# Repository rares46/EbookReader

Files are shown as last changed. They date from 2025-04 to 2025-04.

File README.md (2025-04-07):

# EbookReader
OpenBook eBook Reader

Dispozitivul e-book se bazeaza pe un microcontroller ESP32-C6 si include un afisaj E-Paper.

[Diagrama Bloc](Images/diagram.png)

`Diagrama bloc afiseaza componente:`
- ESP32-C6 (unitate centrala)
- Afisaj E-Paper
- Cititor SD card
- RTC DS3231
- Senzor ambiental BME688
- Control incarcare baterie Li-Po
- Modul flash extern 64MB
- Interfata USB-C
- Circuit de reglare tensiune (LDO)

### BOM - Bill Of Materials

[Fisier BOM](Manufacturing/BOM.csv)
https://ro.mouser.com/
https://www.comet.srl.ro/

Alimentare
- Alimentare principala prin USB-C.
- Reglator de tensiune LDO (IC4 - XC6204A33) pentru conversia de la 5V la 3.3V.
  
Microcontroller
- ESP32-C6 = unitatea principala ce controleaza restul pieselor.
- Se ocupa cu gestionarea interfetei cu utilizatorul, afisajul EPD, comunicatia cu SD card-ul, RTC si senzorul ambiental.
  
Stocare
- Slot microSD pentru stocare.
- Memorie flash externa W25Q512JVSIQ conectata prin SPI pentru firmware suplimentar sau caching.

### Alocarea pinilor ESP32-C6

| Functie | Pin ESP32-C6 | Observatii |
|---|---|---|
| SD Card | IO2, IO3, IO4, IO5 | SPI |
| E-Paper Display | IO8, IO9, IO10 | SPI |
| Senzor BME688 | IO6 (SCL), IO7 (SDA) | I2C |
| RTC DS3231 | IO6 (SCL), IO7 (SDA) | I2C shared |
| Flash extern SPI | IO0, IO1, IO2 | SPI |
| Boot Button | IO9 | Reset GPIO |
| Buton IO | IO10 | Control interfata |
| UART Debug | IO20 (TX), IO21 (RX) | Conexiune seriala |
| Ecran Type Select | IO18, IO19 | Selectare tip e-paper |

Bugs: La piesa SAMACSYS_PARTS_USB4110GFA erori cu Board OUtline Clearance, care sunt datorate piesei cel mai probabil si din cand in cand eorare de Overlap la fir. Daca scot firul si il pun la loc dispare.
La piesa IND_4828-WE-TPC_WRE 2 erori Copper Width, care probabil sunt de la piesa.
  
La directorul images din proiect sunt imagini cu schematic ul, pcb si 3d si diagrama.

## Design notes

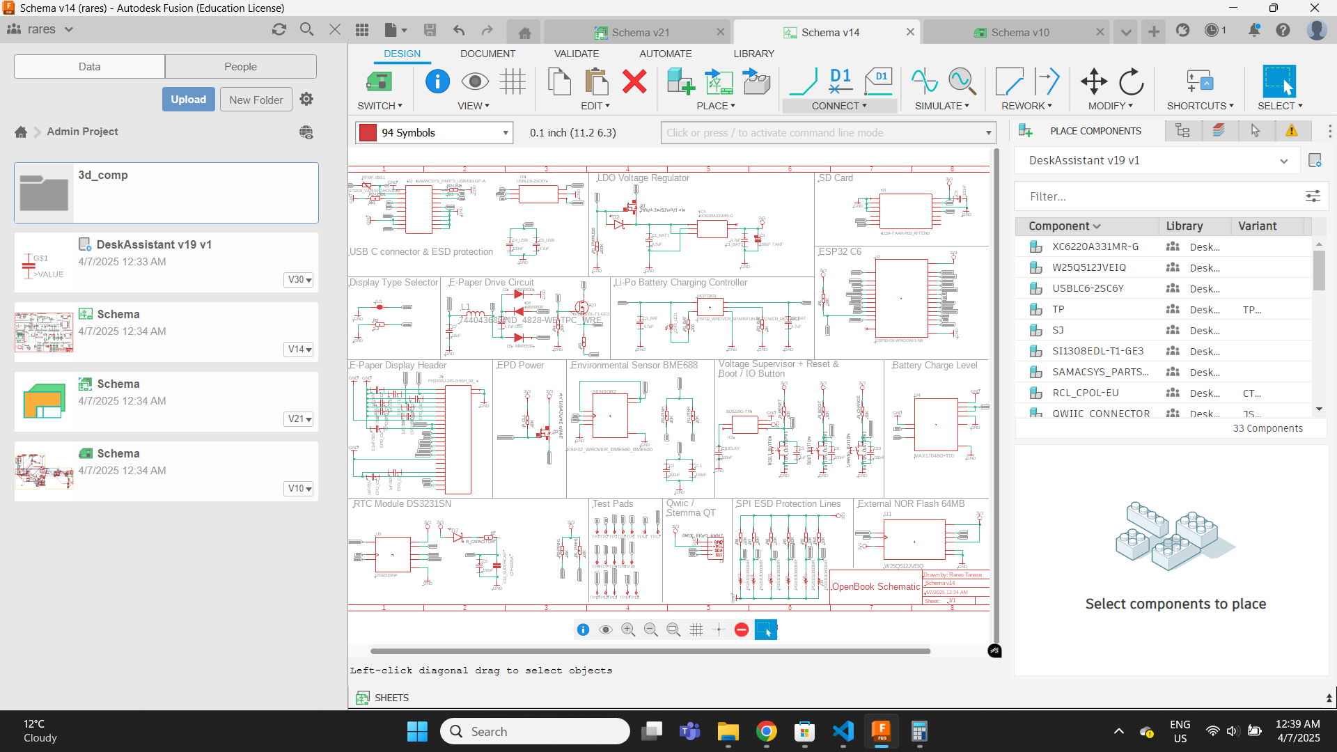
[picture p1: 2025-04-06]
Images/Schematic.png

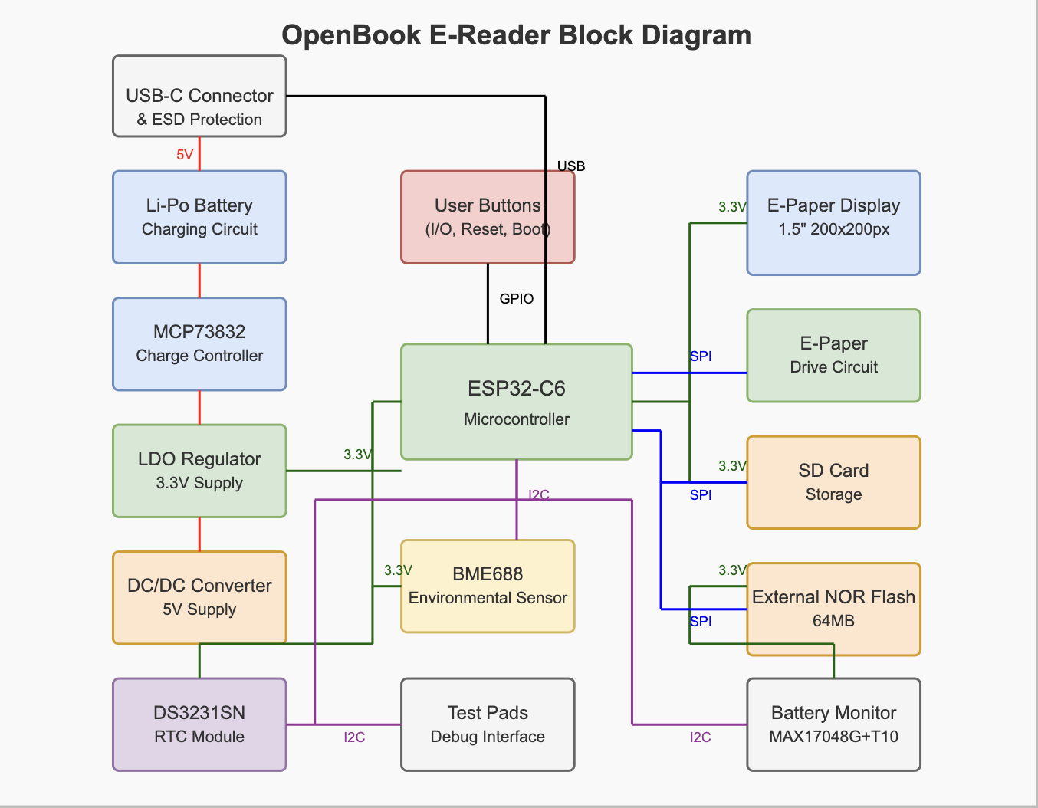
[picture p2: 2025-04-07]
Images/diagram.png

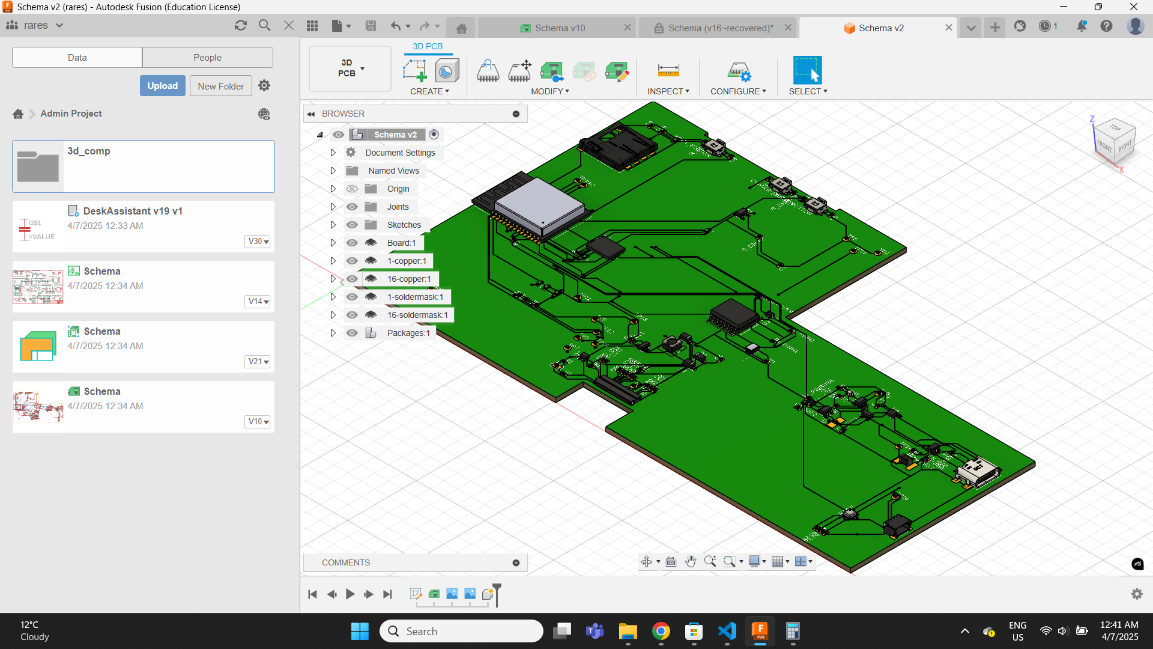
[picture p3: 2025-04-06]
Images/Board.png

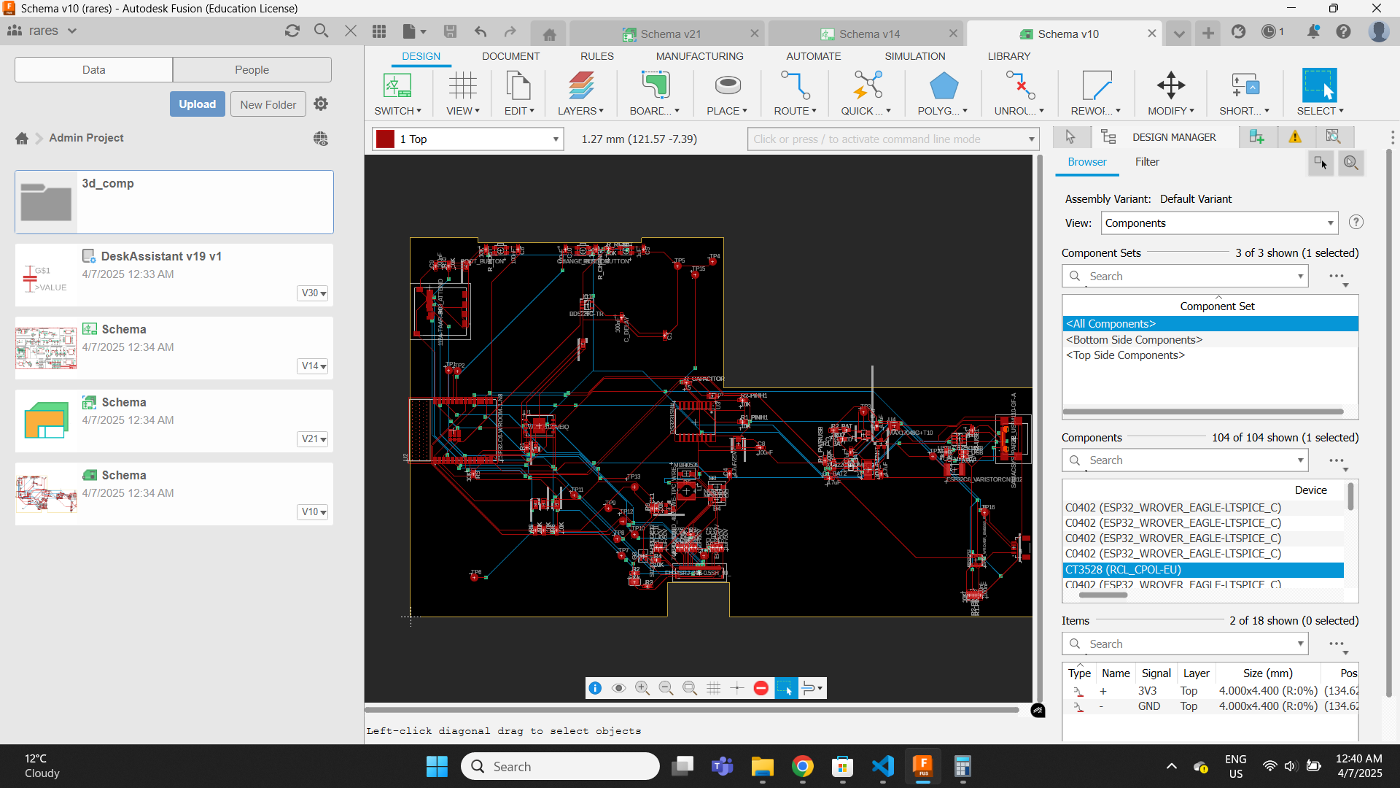
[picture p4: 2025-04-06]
Images/PCB.png

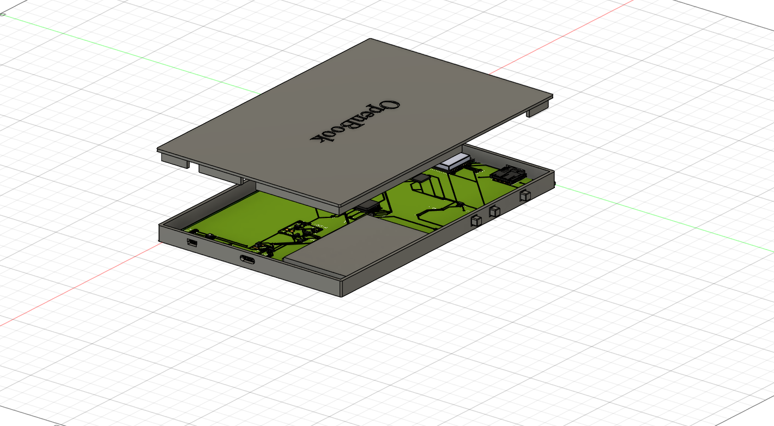
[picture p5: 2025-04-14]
Images/OpenBook Enclosure v1.png

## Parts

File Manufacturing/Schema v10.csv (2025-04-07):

Qty | Value | Device | Package | Parts | Description | ARROW_PART_NUMBER | ARROW_PRICE-STOCK | AVAILABILITY | CENTROID_NOT_SPECIFIED | CHECK_PRICES | COPYRIGHT | DATASHEET | DESCRIPTION | DIGIKEY_DESCRIPTION | DIGIKEY_PART_NUMBER | HEIGHT | LEAD_FREE | MANUFACTURER_NAME | MANUFACTURER_PART_NUMBER | MF | MFR_NAME | MOUSER_PART_NUMBER | MOUSER_PRICE-STOCK | MOUSER_TESTING_PART_NUMBER | MOUSER_TESTING_PRICE-STOCK | MP | MPN | PACKAGE | POPULARITY | PREFIX | PRICE | PROD_ID | PURCHASE-URL | ROHS | SNAPEDA_LINK | SPICEMODEL | SPICEPREFIX | TEMPERATURE_RANGE_HIGH | TEMPERATURE_RANGE_LOW | TP_SIGNAL_NAME | VALUE
1 |  | ADAFRUIT_LEDCHIP-LED0603 | ADAFRUIT_CHIP-LED0603 | CHG_LED | LED
1 |  | ESP32_WROVER_EAGLE-LTSPICE_CC0402 | ESP32_WROVER_EAGLE-LTSPICE_C0402 | C1 | CAPACITOR, European symbol |  |  |  |  |  |  |  |  |  |  |  |  |  |  |  |  |  |  |  |  |  |  |  |  |  |  |  |  |  |  | NONE | C
1 |  | ESP32_WROVER_EAGLE-LTSPICE_RR0402 | ESP32_WROVER_EAGLE-LTSPICE_R0402 | R3 | RESISTOR, European symbol |  |  |  |  |  |  |  |  |  |  |  |  |  |  |  |  |  |  |  |  |  |  |  |  |  |  |  |  |  |  | NONE | R
1 |  | SJ | SJ | SJ1 | SMD solder JUMPER |  |  |  |  |  |  |  |  |  |  |  |  |  |  |  |  |  |  |  |  |  |  |  | 3
1 | 0.1uF/50V | ESP32_WROVER_EAGLE-LTSPICE_CC0402 | ESP32_WROVER_EAGLE-LTSPICE_C0402 | EPD_C5 | CAPACITOR, European symbol |  |  |  |  |  |  |  |  |  |  |  |  |  |  |  |  |  |  |  |  |  |  |  |  |  |  |  |  |  |  | NONE | C
1 | 100K | ESP32_WROVER_EAGLE-LTSPICE_RR0402 | ESP32_WROVER_EAGLE-LTSPICE_R0402 | R1_PWRUSB | RESISTOR, European symbol |  |  |  |  |  |  |  |  |  |  |  |  |  |  |  |  |  |  |  |  |  |  |  |  |  |  |  |  |  |  | NONE | R
8 | 100nF | ESP32_WROVER_EAGLE-LTSPICE_CC0402 | ESP32_WROVER_EAGLE-LTSPICE_C0402 | C.1, C2, C4_USB, C6, C8, C9, C10, C_DELAY | CAPACITOR, European symbol |  |  |  |  |  |  |  |  |  |  |  |  |  |  |  |  |  |  |  |  |  |  |  |  |  |  |  |  |  |  | NONE | C
1 | 100uF TANT | RCL_CPOL-EUCT3528 | RCL_CT3528 | C3 | POLARIZED CAPACITOR, European symbol |  |  |  |  |  |  |  |  |  |  |  |  |  |  |  |  |  |  |  |  |  |  |  | 0 |  |  |  |  |  |  |  | C
16 | 10K | ESP32_WROVER_EAGLE-LTSPICE_RR0402 | ESP32_WROVER_EAGLE-LTSPICE_R0402 | R1, R1-PINH, R1_PINH1, R2-PINH, R2-PINH1, R4, R5, R6, R7, R8, R9, R10, R_BOOT, R_CHANGE, R_CL1, R_RESET | RESISTOR, European symbol |  |  |  |  |  |  |  |  |  |  |  |  |  |  |  |  |  |  |  |  |  |  |  |  |  |  |  |  |  |  | NONE | R
1 | 10uF | ESP32_WROVER_EAGLE-LTSPICE_CC0402 | ESP32_WROVER_EAGLE-LTSPICE_C0402 | C7 | CAPACITOR, European symbol |  |  |  |  |  |  |  |  |  |  |  |  |  |  |  |  |  |  |  |  |  |  |  |  |  |  |  |  |  |  | NONE | C
1 | 112A-TAAR-R03_ATTEND | 112A-TAAR-R03_ATTEND | 112ATAARR03ATTEND | J4 | Micro SD Card Socket, Push-Push Type, Top Mount, SMT, H=1.83mm, 10u |  |  |  |  |  |  |  | Micro SD Card Socket | Push-Push Type | Top Mount | SMT | H=1.83mm | 10u |  |  | 1.9mm |  | ATTEND | 112A-TAAR-R03 ATTEND
1 | 15 | ESP32_WROVER_EAGLE-LTSPICE_RR0402 | ESP32_WROVER_EAGLE-LTSPICE_R0402 | R_CAPACITOR | RESISTOR, European symbol |  |  |  |  |  |  |  |  |  |  |  |  |  |  |  |  |  |  |  |  |  |  |  |  |  |  |  |  |  |  | NONE | R
1 | 1uF | ESP32_WROVER_EAGLE-LTSPICE_CC0402 | ESP32_WROVER_EAGLE-LTSPICE_C0402 | C5 | CAPACITOR, European symbol |  |  |  |  |  |  |  |  |  |  |  |  |  |  |  |  |  |  |  |  |  |  |  |  |  |  |  |  |  |  | NONE | C
9 | 1uF/50V | ESP32_WROVER_EAGLE-LTSPICE_CC0402 | ESP32_WROVER_EAGLE-LTSPICE_C0402 | EPD_C1, EPD_C2, EPD_C6, EPD_C7, EPD_C8, EPD_C9, EPD_C10, EPD_C11, EPD_C12 | CAPACITOR, European symbol |  |  |  |  |  |  |  |  |  |  |  |  |  |  |  |  |  |  |  |  |  |  |  |  |  |  |  |  |  |  | NONE | C
1 | 2.2 | ESP32_WROVER_EAGLE-LTSPICE_RR0402 | ESP32_WROVER_EAGLE-LTSPICE_R0402 | R2 | RESISTOR, European symbol |  |  |  |  |  |  |  |  |  |  |  |  |  |  |  |  |  |  |  |  |  |  |  |  |  |  |  |  |  |  | NONE | R
1 | 200 | ESP32_WROVER_EAGLE-LTSPICE_RR0402 | ESP32_WROVER_EAGLE-LTSPICE_R0402 | R1_BAT | RESISTOR, European symbol |  |  |  |  |  |  |  |  |  |  |  |  |  |  |  |  |  |  |  |  |  |  |  |  |  |  |  |  |  |  | NONE | R
2 | 20V/4.2A/52mO/1.4W | ESP32_WROVER_SPARKFUN-DISCRETESEMI_MOSFET_PCH-DMG2305UX-7 | ESP32_WROVER_SPARKFUN-DISCRETESEMI_SOT23-3 | Q1, Q2 | P-channel MOSFETs |  |  |  |  |  |  |  |  |  |  |  |  |  |  |  |  |  |  |  |  |  |  |  |  |  |  | TRAN-14388 |  |  |  |  |  |  |  |  | 20V/4.2A/52mO/1.4W
1 | 2K | ESP32_WROVER_EAGLE-LTSPICE_RR0402 | ESP32_WROVER_EAGLE-LTSPICE_R0402 | R2_BAT | RESISTOR, European symbol |  |  |  |  |  |  |  |  |  |  |  |  |  |  |  |  |  |  |  |  |  |  |  |  |  |  |  |  |  |  | NONE | R
5 | 4.7uF | ESP32_WROVER_EAGLE-LTSPICE_CC0402 | ESP32_WROVER_EAGLE-LTSPICE_C0402 | C1_BAT, C1_BAT1, C1_BAT2, C2_BAT, C5_USB | CAPACITOR, European symbol |  |  |  |  |  |  |  |  |  |  |  |  |  |  |  |  |  |  |  |  |  |  |  |  |  |  |  |  |  |  | NONE | C
1 | 4.7uF/25V | ESP32_WROVER_EAGLE-LTSPICE_CC0402 | ESP32_WROVER_EAGLE-LTSPICE_C0402 | C4 | CAPACITOR, European symbol |  |  |  |  |  |  |  |  |  |  |  |  |  |  |  |  |  |  |  |  |  |  |  |  |  |  |  |  |  |  | NONE | C
2 | 5k1 | ESP32_WROVER_EAGLE-LTSPICE_RR0402 | ESP32_WROVER_EAGLE-LTSPICE_R0402 | R2-USB, R2-USB1 | RESISTOR, European symbol |  |  |  |  |  |  |  |  |  |  |  |  |  |  |  |  |  |  |  |  |  |  |  |  |  |  |  |  |  |  | NONE | R
1 | 744043680IND_4828-WE-TPC_WRE | 744043680IND_4828-WE-TPC_WRE | IND_4828-WE-TPC_WRE | L1 |  |  |  |  |  |  | Copyright (C) 2024 Ultra Librarian. All rights reserved. |  |  |  |  |  |  |  | 744043680 |  | Wurth Electronics
1 | BD5229G-TR | BD5229G-TR | SOT95P280X125-5N | IC1 | Voltage Detector with Adjustable Delay Time: CMOS processes are utilized to develop high precision, low current consumption CMOS reset ICs that allow arbitrary setting of the delay time. The extensive lineup includes both Nch Open Drain and CMOS output types in a wide range of detection voltages (from 2.3V to 6.0V, in 0.1V steps), enabling selection of the ideal solution based on customer requirements. In addition, the entire series is of course both lead-free and RoHS-compliant. |  |  |  |  |  |  |  | Voltage Detector with Adjustable Delay Time: CMOS processes are utilized to develop high precision | low current consumption CMOS reset ICs that allow arbitrary setting of the delay time. The extensive lineup includes both Nch Open Drain and CMOS output types in a wide range of detection voltages (from 2.3V to 6.0V | in 0.1V steps) | enabling selection of the ideal solution based on customer requirements. In addition | the entire series is of course both lead-free and RoHS-compliant. |  |  | 1.25mm |  | ROHM Semiconductor | BD5229G-TR |  |  | 755-BD5229G-TR | https://www.mouser.co.uk/ProductDetail/ROHM-Semiconductor/BD5229G-TR?qs=4kLU8WoGk0vvnhrrYwdszw%3D%3D
3 | BUTTON_CUSYOMV1 | BUTTON_CUSYOMV1 | MYBUTTON | BOOT_BUTTON, CHANGE_BUTTON, RESET_BUTTON
1 | CPH3225A | CPH3225A | CAPCP3225X100N | C10_SUPERCAP | Cap 0.011F 3.3V 1210 Flat Check availability |  |  | Not in stock |  | https://www.snapeda.com/parts/CPH3225A/Seiko+Instruments/view-part/?ref=eda |  |  | 11 mF (EDLC) Supercapacitor 3.3 V 1210 (3225 Metric) - - |  |  |  |  |  |  | Seiko Instruments |  |  |  |  |  | CPH3225A |  | 1210 Seiko |  |  | None |  | https://www.snapeda.com/api/url_track_click_mouser/?unipart_id=562593&manufacturer=Seiko Instruments&part_name=CPH3225A&search_term=None |  | https://www.snapeda.com/parts/CPH3225A/Seiko+Instruments/view-part/?ref=snap
1 | DS3231SN# | DS3231SN# | SOIC127P1032X265-16N | U3 | Real Time Clock Serial 16-Pin SOIC W T/R Check availability |  |  | In Stock |  | https://www.snapeda.com/parts/DS3231SN%23/Analog+Devices/view-part/?ref=eda |  |  | Extremely Accurate I²C-Integrated RTC/TCXO/Crystal |  |  |  |  |  |  | Analog Devices |  |  |  |  |  | DS3231SN# |  | SOIC-16 Maxim |  |  | None |  | https://www.snapeda.com/api/url_track_click_mouser/?unipart_id=99048&manufacturer=Analog Devices&part_name=DS3231SN#&search_term=None |  | https://www.snapeda.com/parts/DS3231SN%23/Analog+Devices/view-part/?ref=snap
1 | ESP32-C6-WROOM-1-N8 | ESP32-C6-WROOM-1-N8 | XCVR_ESP32-C6-WROOM-1-N8 | U2 | Check availability |  |  | In Stock |  | https://www.snapeda.com/parts/ESP32-C6-WROOM-1-N8/Espressif+Systems/view-part/?ref=eda |  |  | Multiprotocol Modules ESP32-C6 module | Wi-Fi 6 in 2.4 GHz band | Bluetooth 5 | Zigbee 3.0 and Thread. ESP34-WROOM Compatible - ENGINEERING SAMPLE |  |  |  |  |  |  | Espressif Systems |  |  |  |  |  | ESP32-C6-WROOM-1-N8 |  | None |  |  | None |  |  |  | https://www.snapeda.com/parts/ESP32-C6-WROOM-1-N8/Espressif+Systems/view-part/?ref=snap
1 | ESP32C6_VARISTORCN1812 | ESP32C6_VARISTORCN1812 | ESP32C6_VARISTOR_CT/CN1812 | PFMF.050.1 | VARISTOR |  |  |  |  |  |  |  |  |  |  |  |  |  |  |  |  |  |  |  |  |  |  |  | 0
2 | ESP32_WROVER_AVX---SD0805S020S1R0_AVX_SD0805S020S1R0_0_0AVX_SD0805S020S1R0_0_0 | ESP32_WROVER_AVX---SD0805S020S1R0_AVX_SD0805S020S1R0_0_0AVX_SD0805S020S1R0_0_0 | ESP32_WROVER_AVX---SD0805S020S1R0_AVX_SD0805S020S1R0_0 | D2, D7 | Schottky Barrier Rectifier Diode |  |  |  | No |  |  | http://datasheets.avx.com/schottky.pdf |  | DIODE SCHOTTKY 20V 1A 0805 | 478-7800-1-ND |  | yes |  |  | AVX |  | 581-SD0805S020S1R0 |  |  |  |  |  | 0805 (2012 metric) |  | D |  |  |  | yes |  |  |  | +125°C | -55°C
1 | ESP32_WROVER_BME680_BME680 | ESP32_WROVER_BME680_BME680 | ESP32_WROVER_BME680_PSON80P300X300X100-8N | SENSOR2 | Integrated Environmental Unit |  |  | Unavailable |  |  |  |  | Integrated Environmental Unit |  |  |  |  |  |  | Bosch Sensortec |  |  |  |  |  | BME680 |  | LGA-8 Bosch Tools |  |  | None
1 | ESP32_WROVER_SPARKFUN-IC-POWER_MCP73831 | ESP32_WROVER_SPARKFUN-IC-POWER_MCP73831 | ESP32_WROVER_SPARKFUN-IC-POWER_SOT23-5 | MCP73831 | MCP73831T Li-Ion, Li-Pol Controller |  |  |  |  |  |  |  |  |  |  |  |  |  |  |  |  |  |  |  |  |  |  |  |  |  |  | IC-09995
1 | FH34SRJ-24S-0.5SH_99_ | FH34SRJ-24S-0.5SH_99_ | FH34SRJ24S05SH99 | J1 | (0.50mm) Surface Mount, Right Angle |  |  |  |  |  |  |  | 24 Position FFC | FPC Connector Contacts | (0.50mm) Surface Mount | Right Angle |  |  | 1.1mm |  | Hirose | FH34SRJ-24S-0.5SH(99) |  |  | 798-FH34SRJ24S05SH99 | https://www.mouser.co.uk/ProductDetail/Hirose-Connector/FH34SRJ-24S-0.5SH99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
1 | MAX17048G+T10 | MAX17048G+T10 | SON50P200X200X80-9N | U4 | Check availability |  |  | In Stock |  | https://www.snapeda.com/parts/MAX17048G+T10/Analog+Devices/view-part/?ref=eda |  |  | 3µA 1-Cell/2-Cell Fuel Gauge with ModelGauge |  |  |  |  |  |  | Analog Devices |  |  |  |  |  | MAX17048G+T10 |  | TDFN-8 Maxim |  |  | None |  | https://www.snapeda.com/api/url_track_click_mouser/?unipart_id=329239&manufacturer=Analog Devices&part_name=MAX17048G+T10&search_term=None |  | https://www.snapeda.com/parts/MAX17048G+T10/Analog+Devices/view-part/?ref=snap
3 | MBR0530 | MBR0530 | SOD3716X135N | D3, D4, D5 | ON SEMICONDUCTOR - MBR0530 - DIODE, SCHOTTKY, 0.5A, 30V, SOD-123 |  |  | In Stock |  | https://www.snapeda.com/parts/MBR0530/Onsemi/view-part/?ref=eda |  |  | Diode Schottky 30 V 500mA Surface Mount SOD-123 |  |  |  |  |  |  | ON Semiconductor |  |  |  |  |  | MBR0530 |  | SOD-123-2 ON Semiconductor |  |  | None |  | https://www.snapeda.com/api/url_track_click_mouser/?unipart_id=179458&manufacturer=ON Semiconductor&part_name=MBR0530&search_term=None |  | https://www.snapeda.com/parts/MBR0530/Onsemi/view-part/?ref=snap
6 | PGB1010603MR | PGB1010603MR | DIOC1608X36N | D6, D8, D9, D10, D11, D12 | Check availability |  |  | In Stock |  | https://www.snapeda.com/parts/PGB1010603MR/Littelfuse/view-part/?ref=eda |  |  | 150V (Typ) Clamp - Ipp Tvs Diode Surface Mount 0603 (1608 Metric) |  |  |  |  |  |  | Littelfuse Inc. |  |  |  |  |  | PGB1010603MR |  | 0603 Littelfuse Inc. |  |  | None |  | https://www.snapeda.com/api/url_track_click_mouser/?unipart_id=5659453&manufacturer=Littelfuse Inc.&part_name=PGB1010603MR&search_term=None |  | https://www.snapeda.com/parts/PGB1010603MR/Littelfuse/view-part/?ref=snap
1 | QWIIC_RIGHT_ANGLE | QWIIC_CONNECTORJS-1MM | JST04_1MM_RA | J3 | SparkFun I2C Standard Qwiic Connector |  |  |  |  |  |  |  |  |  |  |  |  |  |  |  |  |  |  |  |  |  |  |  |  |  |  | CONN-13694 |  |  |  |  |  |  |  |  | QWIIC_RIGHT_ANGLE
1 | SAMACSYS_PARTS_USB4110-GF-A | SAMACSYS_PARTS_USB4110-GF-A | SAMACSYS_PARTS_USB4110GFA | J2 | CONN USB 2.0 TYPE-C R/A SMT |  |  |  |  |  |  |  | CONN USB 2.0 TYPE-C R/A SMT |  |  | 3.26mm |  | GCT (GLOBAL CONNECTOR TECHNOLOGY) | USB4110-GF-A |  |  | 640-USB4110-GF-A | https://www.mouser.co.uk/ProductDetail/GCT/USB4110-GF-A?qs=KUoIvG%2F9IlYiZvIXQjyJeA%3D%3D
1 | SI1308EDL-T1-GE3 | SI1308EDL-T1-GE3 | SOT65P210X110-3N | Q3 | MOSFET N-Ch 30V 1.5A TrenchFET SC70 Vishay Si1308EDL-T1-GE3 N-channel MOSFET Transistor, 1.5 A, 30 V, 3-Pin SC-70 |  |  | In Stock |  | https://www.snapeda.com/parts/SI1308EDL-T1-GE3/Vishay+Siliconix/view-part/?ref=eda |  |  | Si1308EDL-T1-GE3 N-channel MOSFET Transistor | 1.5 A | 30 V | 3-Pin SC-70 | Siliconix / Vishay SI1308EDL-T1-GE3 |  |  |  |  |  |  | Vishay Siliconix |  |  |  |  |  | SI1308EDL-T1-GE3 |  | SOT-323 Vishay Semiconductor |  |  | None |  | https://www.snapeda.com/api/url_track_click_mouser/?unipart_id=274603&manufacturer=Vishay Siliconix&part_name=SI1308EDL-T1-GE3&search_term=None |  | https://www.snapeda.com/parts/SI1308EDL-T1-GE3/Vishay+Siliconix/view-part/?ref=snap
17 | TPTP20R | TPTP20R | TP20R | TP1, TP2, TP3, TP4, TP5, TP6, TP7, TP8, TP9, TP10, TP11, TP12, TP13, TP14, TP15, TP16, TP17 | Test pad |  |  |  |  |  |  |  |  |  |  |  |  |  |  |  |  |  |  |  |  |  |  |  | 2
1 | USBLC6-2SC6Y | USBLC6-2SC6Y | SOT95P280X145-6N | D1 | Low Cap. ESD Protection Auto SOT-23-6 STMicroelectronics USBLC6-2SC6Y, Dual Uni-Directional TVS Diode Array, 6-Pin SOT-23 |  |  | In Stock |  | https://www.snapeda.com/parts/USBLC6-2SC6Y/STMicroelectronics/view-part/?ref=eda |  |  | 17V Clamp 5A (8/20µs) Ipp Tvs Diode Surface Mount SOT-23-6 |  |  |  |  |  |  | STMicroelectronics |  |  |  |  |  | USBLC6-2SC6Y |  | SOT-23-6 STMicroelectronics |  |  | None |  |  |  | https://www.snapeda.com/parts/USBLC6-2SC6Y/STMicroelectronics/view-part/?ref=snap
1 | W25Q512JVEIQ | W25Q512JVEIQ | SON127P600X800X80-9N | U1 | Check availability |  |  | In Stock |  | https://www.snapeda.com/parts/W25Q512JVEIQ/Winbond+Electronics/view-part/?ref=eda |  |  | FLASH - NOR Memory IC 512Mb (64M x 8) SPI - Quad I/O 133 MHz 8-WSON (8x6) |  |  |  |  |  |  | Winbond Electronics |  |  |  |  |  | W25Q512JVEIQ |  | Package |  |  | None |  |  |  | https://www.snapeda.com/parts/W25Q512JVEIQ/Winbond+Electronics/view-part/?ref=snap
1 | XC6220A331MR-G | XC6220A331MR-G | SOT95P280X120-5N | IC4 | LDO Voltage Regulators |  |  |  |  |  |  |  | LDO Voltage Regulators |  |  | 1.2mm |  | Torex | XC6220A331MR-G |  |  | 865-XC6220A331MR-G | https://www.mouser.co.uk/ProductDetail/Torex-Semiconductor/XC6220A331MR-G?qs=AsjdqWjXhJ8ZSWznL1J0gg%3D%3D

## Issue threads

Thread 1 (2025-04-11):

[Quick Fix] Fix R3 Value in E-Paper Drive Circuit

ScourgeNest, 2025-04-11:
### Description
The resistor `R3` in the **E-Paper Drive Circuit** schematic is missing its value. This could cause confusion during assembly or simulation, as it's unclear what value should be used.

---

### Reproduce
1. Open the schematic file
2. Locate the MOSFET `Q3` (SI1308EDL-T1-GE3)
3. Find the resistor `R3` connected between the `RESE` net and the source of `Q3`
4. Observe that `R3` has no value assigned
5. See attached images for reference
   - **fig 1**: The E-Paper Drive Circuit

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

   - **fig 2**: Zoomed-in view of R3 missing its value

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

---

### Expected Behavior
`R3` should have a value of **0.47Ω**

---

### Suggested Fix
- Edit the schematic to assign the value `0.47Ω` to resistor `R3`
- Update the schematic files and regenerate the BOM if applicable

Closed 2025-04-13.

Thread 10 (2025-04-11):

Floating 3D Models (Not Aligned with PCB)

ScourgeNest, 2025-04-11:
# 📦 Floating 3D Models (Not Aligned with PCB)

### 📝 Description
Several components in the current Fusion 360 project have incorrectly positioned **3D models** — they appear to be "floating" **above the PCB** instead of being properly aligned with the board surface. This issue results in **pins not touching their corresponding pads**, which affects mechanical accuracy, visual renderings, and could even lead to soldering issues in manufacturing previews.

---

### ⚠️ Affected Components

- `ESP32-C6-WROOM-1-N8`

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

- `112A-TAAR-R03_ATTEND`

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

- `744043680IND_4828-WE-TPC_WRE`

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

These components appear visually disconnected from the PCB in the 3D view, with the entire model hovering above the board surface.

---

### 🔁 Reproduce

1. 🛠️ Open the Fusion 360 board layout in **3D view**
2. 🧭 Inspect the above components individually
3. 🆙 Notice that the 3D body is elevated (levitating) above the PCB
4. ❌ Pins do not make physical contact with the pad footprints
5. 🧪 Try generating a rendering or exploded view — models will appear misaligned

---

### ✅ Suggested Fix

- 🔧 Adjust the **axis position** of the 3D model for each affected component
- 🧲 Use **Align** or **Move** commands in Fusion 360 to properly sit the model on the PCB
- 📏 Ensure that the **pin tips** align correctly with the center of their corresponding **pads**
- 💾 Save and update the 3D model alignment in the library, if reused
- 🔁 Review all major components to ensure proper model positioning

---

### 💡 Notes

Correct 3D alignment is important for mechanical integration (e.g., enclosures, clearances) and visual validation. Improper positioning may lead to incorrect assumptions during review or manufacturing setup.

Closed 2025-04-14.

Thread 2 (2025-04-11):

Add PCB Cutout and Via Stitching Under Antenna

ScourgeNest, 2025-04-11:
# Add PCB Cutout and Via Stitching Under Antenna

### Description
The current PCB layout does not include a cutout (copper keep-out) under the antenna area. Additionally, via stitching is missing underneath the antenna, which can negatively impact RF performance and cause impedance mismatches or detuning.

---

### Reproduce
1. Open the PCB layout file
2. Locate the antenna section
3. Observe that:
   - There is no copper cutout (no ground plane clearance) under the antenna
   - There is no via stitching connecting the top and bottom ground planes around/under the antenna
4. See attached screenshots for reference
   - **fig 1**: Antenna zone with copper still present underneath

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

---

### Expected Behavior
- There should be a **copper cutout (keep-out zone)** under the antenna to reduce coupling and improve efficiency
- There should be **via stitching** around and under the antenna area to provide proper RF grounding and shielding

---

### Suggested Fix
- Add a copper keep-out zone under the antenna on all layers
- Add via stitching along the antenna perimeter and near the ground reference edge

Closed 2025-04-14.

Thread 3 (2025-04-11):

Add Full GND Plane Using Polygon Pour + Via Stitching

ScourgeNest, 2025-04-11:
# Add Full GND Plane Using Polygon Pour + Via Stitching

### Description
The PCB currently lacks a proper ground plane covering the entire board. A solid GND plane is essential for signal integrity. In Fusion 360, the Polygon Pour tool should be used to add a ground plane on both the **Top** and **Bottom** layers. Additionally, **via stitching** is needed to ensure the ground planes are electrically connected and free of floating sections or isolated islands.

---

### Reproduce
1. Open the PCB layout in Fusion 360
2. Observe the current copper layers
3. Notice that:
   - There is no complete GND polygon pour across the board
   - There is no via stitching connecting the top and bottom GND layers
4. See attached screenshots for reference
   - **fig 1**: Missing GND pour  (a picture with the entire PCB Board)

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

---

### Expected Behavior
- A **polygon pour** should cover the entire PCB area for both the **Top** and **Bottom** layers, assigned to the GND net
- **Via stitching** should be placed throughout the board, especially near high-speed traces and around the perimeter, to connect the ground planes effectively

---

### Suggested Fix
- Use the **Polygon Pour** tool in Fusion 360 to add GND pours on both top and bottom layers
- Ensure proper clearance and net assignment (GND)
- Add **via stitching** throughout the board with appropriate spacing (e.g. 1-2 mm apart), especially around the edges and signal-critical areas
- Verify there are no isolated GND islands or unconnected copper zones

Closed 2025-04-14.

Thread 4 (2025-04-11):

Add Correct 3D Model for Test Pads

ScourgeNest, 2025-04-11:
# Add Correct 3D Model for Test Pads

### Description
The current 3D model used for the test pads appears to be similar to the one used for capacitors or resistors. This causes visual confusion and incorrect representation in the 3D PCB view, especially after pushing the PCB to 3D. Test pads should have a distinct and accurate 3D model to reflect their true physical footprint.

---

### Reproduce
1. Open the PCB project
2. Push the PCB to 3D (e.g., using the "Push PCB to 3D" feature in Fusion 360)
3. Locate any of the Test Pads
4. Observe that the 3D model used is identical or very similar to that of a generic SMD resistor
5. See attached image for reference
   - **fig 1**: Incorrect 3D model for Test Pad (Here is a resistor and a Test Pad that have the same 3D Model)

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

---

### Expected Behavior
Each Test Pad should have a flat and minimalistic 3D model that visually and physically matches a test point, not a component with a body (e.g., resistor/capacitor).

---

### Suggested Fix
- Create a custom 3D model for the Test Pad
- Ensure the model is low-profile, typically a circular or rectangular copper pad without body height
- Assign this model to all Test Pad components in the library
- Here’s a useful guide for creating a 3D model for Test Pads:
  👉 *[Test_Pad_3D_Model](https://youtu.be/xlrdBonNlCA)*

Closed 2025-04-14.

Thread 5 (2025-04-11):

Project Structure Is Not Respected

ScourgeNest, 2025-04-11:
# Project Structure Is Not Respected

### Description
The current structure of the project repository does not follow the agreed-upon format. Maintaining a consistent folder and file structure is essential for clarity, usability, and automation (e.g. working links in README.md). Several key elements are either missing, misnamed, or incomplete.

---

### Expected Project Structure

-  Hardware
|-- schematic file (.sch)
|-- board file (.brd)
-  Manufacturing
|-- gerbers.zip
|-- Bill of Materials file (.csv)
|-- Pick and Place file (.csv)
-  Mechanical
|-- 3D file with the complete device (PCB + battery + display + case) - exploded view (.step)
|-- Fusion360 3D file with the full device
-  Images
|-- images with renderings of the device, board, etc.
-LICENSE
- README.md

---

### Current Project Structure (Issues Identified)
- **Hardware**
  ✅ Contains both `.sch` and `.brd` files

- **Manufacturing**
  ❌ Missing `gerbers.zip`
  ⚠️ The `.bom` file has an **unclear or generic filename** ("Schema v10.csv", which I think that is outdated), which causes GitHub to throw a `404 NOT FOUND` when clicking the BOM link in `README.md`
  ✅ Contains the `.csv` file

- **Mechanical**
  ⚠️ Only contains the PCB model in Fusion 360
  ❌ Missing case, battery, and display in the model
  ❌ No exploded view `.step` file of the full assembly

- **Images**
  ⚠️ Images are **too few** and **not high quality** (screenshots instead of rendered views)
  ⚠️ Image filenames are not descriptive or organized
  ❗ Images should be created using **Fusion 360's render tool**, not screen captures

- **LICENSE / README.md**
  ✅ Present
  ⚠️ README.md contains a **broken link to the BOM file**, due to the filename mismatch

---

### Suggested Fix
- Rename the BOM file to a proper name (e.g. `BOM.csv`) to match the README link
- Add the missing `gerbers.zip` to the `Manufacturing` folder
- Create a full mechanical model that includes PCB + display + battery + case
- Export and add a `.step` file with an exploded view of the full device
- Generate high-quality rendered images using Fusion 360
- Rename image files to be descriptive (e.g. `pcb_top_render.png`, `exploded_view.png`)
- Double-check that all links in `README.md` work correctly

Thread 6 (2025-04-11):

Overlapping Wires in SAMACSYS_PARTS_USB4110-GF-A Component

ScourgeNest, 2025-04-11:
# Overlapping Wires in SAMACSYS_PARTS_USB4110-GF-A Component

### Description
In the current Fusion 360 schematic/layout, the component `SAMACSYS_PARTS_USB4110-GF-A` has **20 wire-to-wire overlaps**. These overlaps are detected as **ERC (Electrical Rule Check) errors**. They can cause design validation issues, reduce schematic readability, and impact manufacturing reliability.

Proper wire routing is essential to maintain signal clarity and ensure the design passes all electrical rule checks.

---

### Reproduce

1. Open the Fusion 360 project containing the schematic
2. Navigate to the `SAMACSYS_PARTS_USB4110-GF-A` component
3. Run the **Electrical Rule Check (ERC)**
4. Observe that **20 wire-to-wire overlaps** are reported within this component
5. Visually confirm the overlapping wires in the schematic editor

---

### Suggested Fix

- Manually reroute the wires in the `SAMACSYS_PARTS_USB4110-GF-A` component
- Avoid overlapping wire paths by adjusting angles and trace positions
- Use Fusion 360’s routing and snapping tools to maintain clean paths
- Re-run the Electrical Rule Check (ERC) to confirm resolution

Closed 2025-04-14.

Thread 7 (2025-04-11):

Board Outline Clearance Issues in SAMACSYS_PARTS_USB4110-GF-A Component

ScourgeNest, 2025-04-11:
# 🚧 Board Outline Clearance Issues in SAMACSYS_PARTS_USB4110-GF-A Component

### 📝 Description
The component `SAMACSYS_PARTS_USB4110-GF-A` is generating **21 Board Outline Clearance errors** during design validation. These errors are identified when running the **ERC (Electrical Rule Check)** in Fusion 360.

The root cause appears to be the **proximity of the component’s pads to its mechanical hole**, which violates board outline clearance rules. This can lead to manufacturing issues or mechanical interference in the final product.

---

### 🔁 Reproduce

1. 🔧 Open the Fusion 360 PCB layout containing the component
2. 📍 Locate the `SAMACSYS_PARTS_USB4110-GF-A` footprint on the board
3. 🧪 Run the **ERC (Electrical Rule Check)**
4. ❗ 21 Board Outline Clearance errors will be reported for this component
5. 🔍 Inspect the footprint — notice how the pads are placed too close to the hole inside the component

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

---

### ✅ Suggested Fix

- 🛠️ Modify the footprint of `SAMACSYS_PARTS_USB4110-GF-A`
- ↔️ Increase the distance between the component pads and the central hole
- 📐 Ensure spacing complies with the board outline clearance rules
- 🔁 Re-run the ERC to verify the issue is resolved
- 💾 Save and update the component library accordingly

Closed 2025-04-14.

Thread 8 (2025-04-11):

Pads Too Small in IND_4828-WE-TPC_WRE Component

ScourgeNest, 2025-04-11:
# 📏 Pads Too Small in IND_4828-WE-TPC_WRE Component

### 📝 Description
The component `IND_4828-WE-TPC_WRE` has **pads that are too small**, this issue also triggers **2 Copper Width ERC errors** during validation in Fusion 360. These errors indicate that the copper traces connected to the pads do not meet the required minimum width constraints due to the pad dimensions.

---

### 🔁 Reproduce

1. 🔧 Open the Fusion 360 PCB layout that includes the `IND_4828-WE-TPC_WRE` component
2. 📏 Inspect the size of the pads in the PCB editor
3. 🧪 Run the **Electrical Rule Check (ERC)**
4. ❗ Observe that **2 Copper Width errors** are reported

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

---

### ✅ Suggested Fix

- 🛠️ Modify the footprint for `IND_4828-WE-TPC_WRE`
- ➕ Increase the pad size to accommodate proper trace width and soldering area
- 💾 Update the library component with the new footprint
- 🔁 Re-run ERC to confirm the issue is resolved
- ✅ Ensure that the trace widths now meet the minimum required copper width rules

Closed 2025-04-14.

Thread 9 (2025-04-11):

Power Traces Too Thin (Below 0.3mm Requirement)

ScourgeNest, 2025-04-11:
# ⚡ Power Traces Too Thin (Below 0.3mm Requirement)

### 📝 Description
According to the project requirement:

> "Traseele de alimentare (VCC, VUSB, VBUS, 3V3 etc.) trebuie rutate folosind width = 0.3mm, semnalele de date cu minimum width de 0.15mm"

All **power traces** (e.g., VCC, VUSB, VBUS, 3V3) must be routed with a **minimum width of 0.3 mm**. However, in the current PCB design, power traces are routed with a width of **0.1524 mm**, which is significantly below the required value.

This discrepancy can lead to excessive voltage drop, overheating, and failure to meet current-carrying capacity standards.

---

### 🔁 Reproduce

1. 🔧 Open the PCB layout in Fusion 360
2. 🔍 Select any power trace (e.g., VBUS, 3V3)
3. 🧾 Right-click → Properties
4. ❗ Observe that the trace width is set to **0.1524 mm**
5. 📏 Compare against the design requirement of **0.3 mm minimum**

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

---

### ✅ Suggested Fix

- ✏️ Manually select and update all power traces to have a width of **≥ 0.3 mm**
- ⚙️ Use net classes or custom rule sets in Fusion 360 to enforce proper width per net (e.g., "Power" class)
- 🔁 Re-run ERC/DRC after adjustments
- ✅ Double-check all power nets (VCC, VUSB, VBUS, 3V3, etc.) for compliance

Closed 2025-04-14.

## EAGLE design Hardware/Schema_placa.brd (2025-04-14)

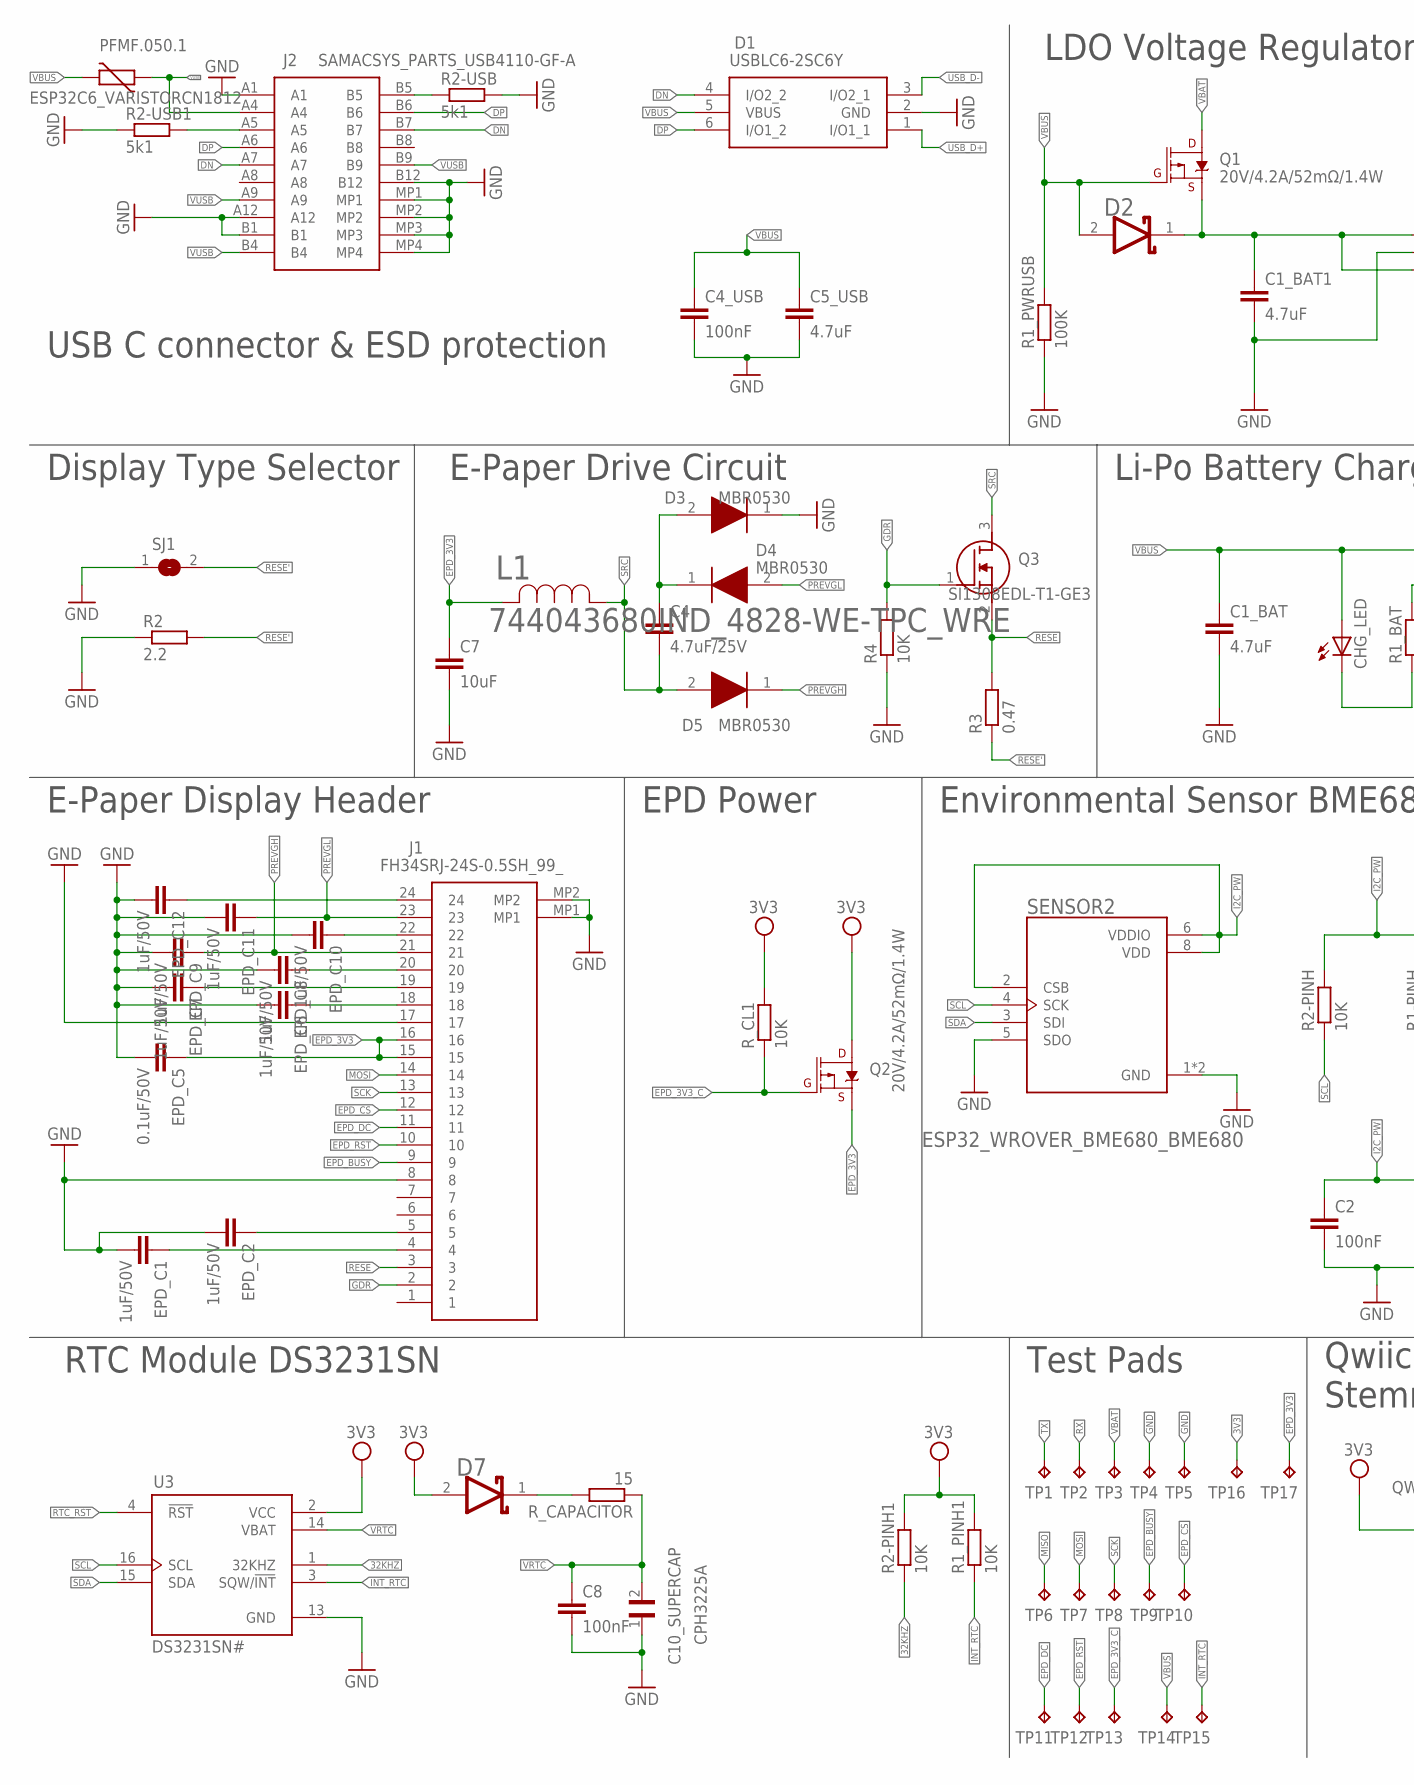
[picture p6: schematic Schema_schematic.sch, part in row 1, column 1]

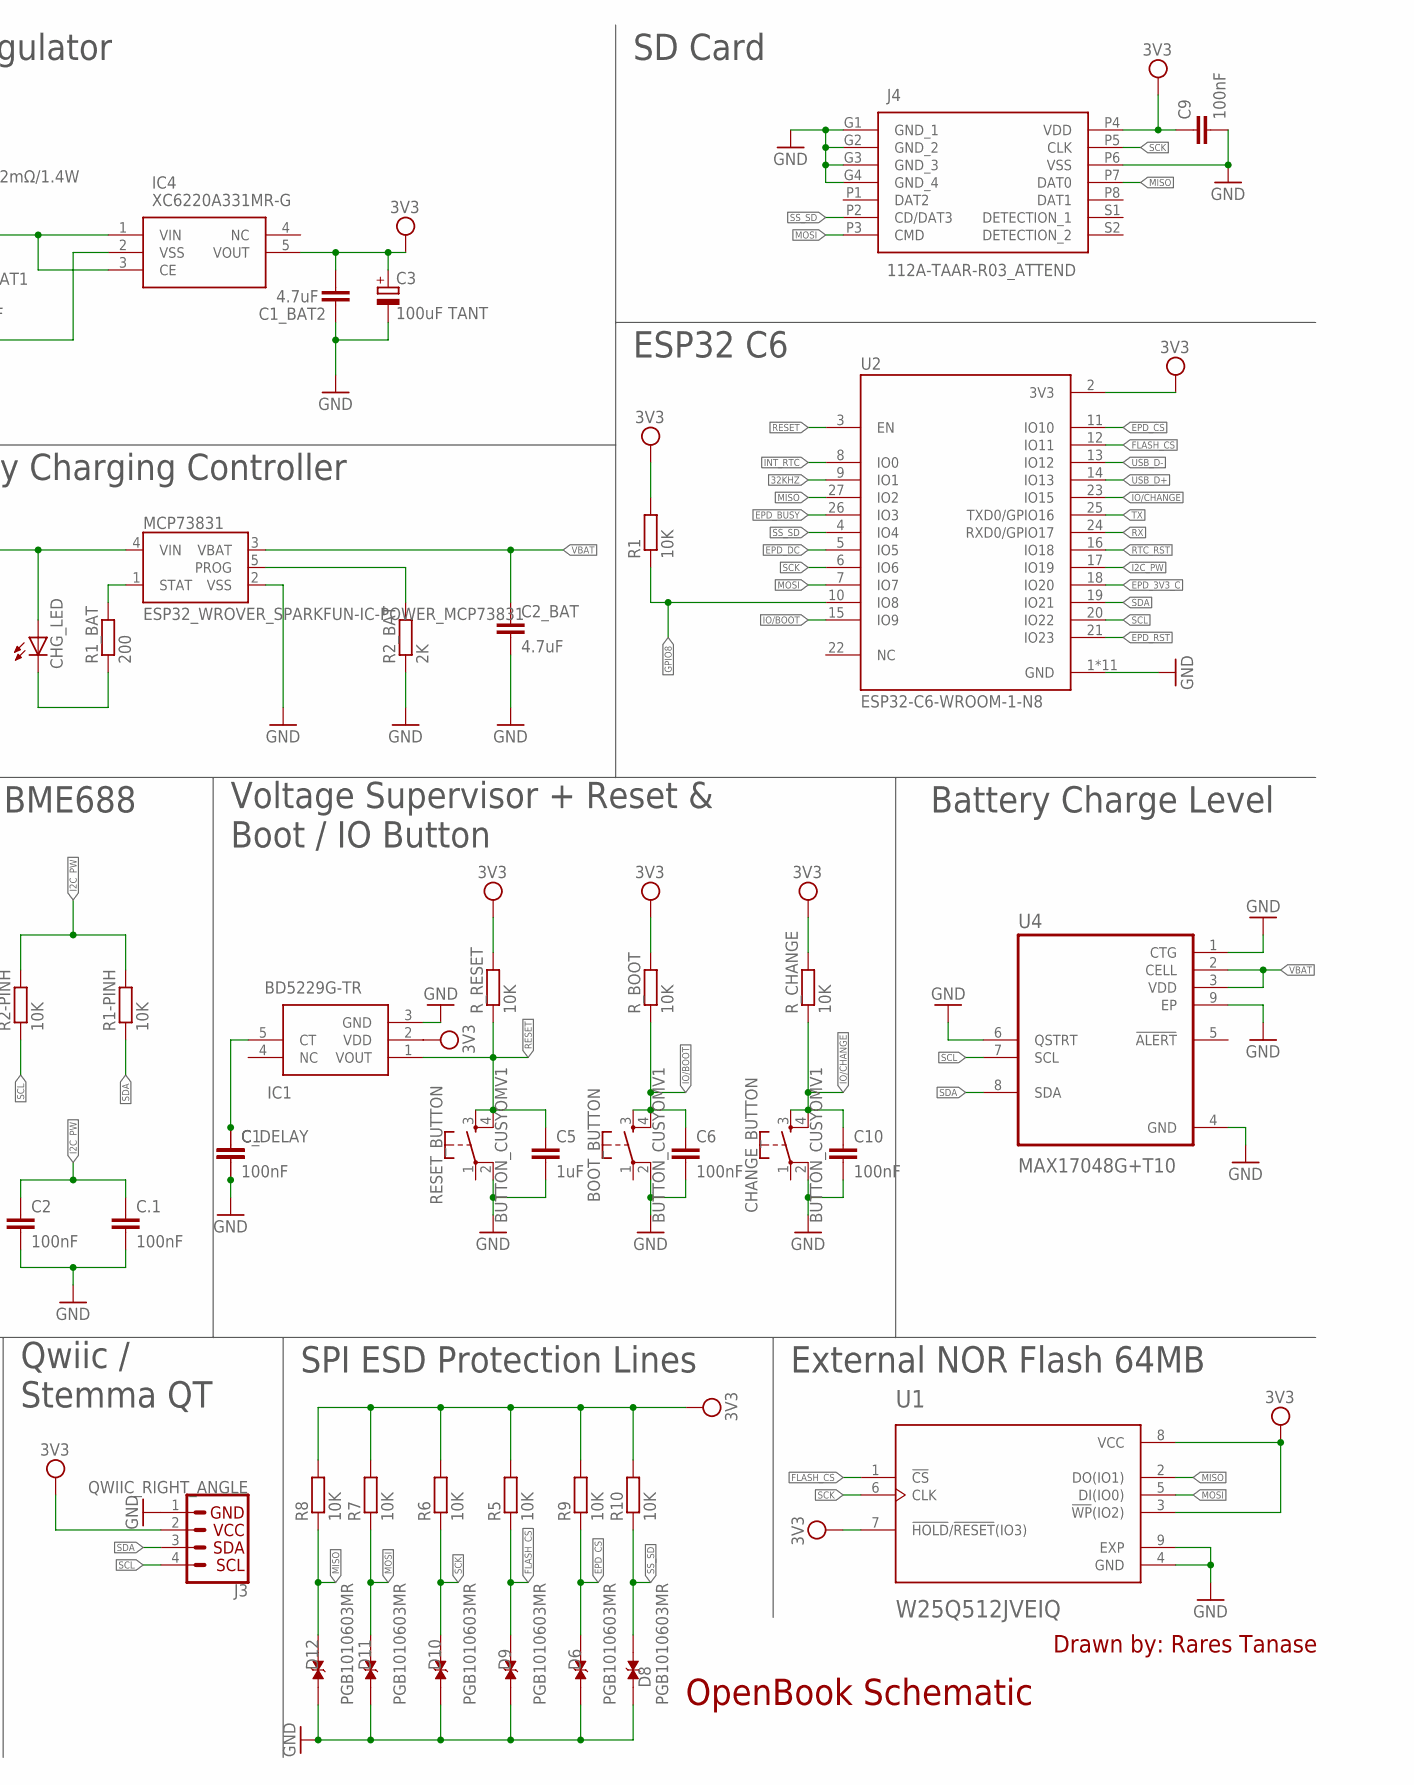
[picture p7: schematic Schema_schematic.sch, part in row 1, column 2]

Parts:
BOOT_BUTTON: BUTTON_CUSYOMV1; MYBUTTON
C1: ESP32_WROVER_EAGLE-LTSPICE_CC0402; ESP32_WROVER_EAGLE-LTSPICE_C0402
C1_BAT, C1_BAT1, C1_BAT2, C2_BAT, C5_USB: 4.7uF; ESP32_WROVER_EAGLE-LTSPICE_C0402
C2, C4_USB, C6, C8, C9, C10, C.1: 100nF; ESP32_WROVER_EAGLE-LTSPICE_C0402
C3: 100uF TANT; RCL_CT3528
C4: 4.7uF/25V; ESP32_WROVER_EAGLE-LTSPICE_C0402
C5: 1uF; ESP32_WROVER_EAGLE-LTSPICE_C0402
C7: 10uF; ESP32_WROVER_EAGLE-LTSPICE_C0402
C10_SUPERCAP: CPH3225A; CAPCP3225X100N
CHANGE_BUTTON: BUTTON_CUSYOMV1; MYBUTTON
CHG_LED: ADAFRUIT_LEDCHIP-LED0603; ADAFRUIT_CHIP-LED0603
C_DELAY: 100nF; ESP32_WROVER_EAGLE-LTSPICE_C0402
D1: USBLC6-2SC6Y; SOT95P280X145-6N
D2, D7: ESP32_WROVER_AVX---SD0805S020S1R0_AVX_SD0805S020S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; ESP32_WROVER_AVX---SD0805S020S1R0_AVX_SD0805S020S1R0_0
D3, D4, D5: MBR0530; SOD3716X135N
D6, D8, D9, D10, D11, D12: PGB1010603MR; DIOC1608X36N
EPD_C1, EPD_C2, EPD_C6, EPD_C7, EPD_C8, EPD_C9, EPD_C10, EPD_C11, EPD_C12: 1uF/50V; ESP32_WROVER_EAGLE-LTSPICE_C0402
EPD_C5: 0.1uF/50V; ESP32_WROVER_EAGLE-LTSPICE_C0402
IC1: BD5229G-TR; SOT95P280X125-5N
IC4: XC6220A331MR-G; SOT95P280X120-5N
J1: FH34SRJ-24S-0.5SH_99_; FH34SRJ24S05SH99
J2: SAMACSYS_PARTS_USB4110-GF-A; SAMACSYS_PARTS_USB4110GFA
J3: QWIIC_RIGHT_ANGLE; JST04_1MM_RA
J4: 112A-TAAR-R03_ATTEND; 112ATAARR03ATTEND
L1: 744043680IND_4828-WE-TPC_WRE; IND_4828-WE-TPC_WRE
MCP73831: ESP32_WROVER_SPARKFUN-IC-POWER_MCP73831; ESP32_WROVER_SPARKFUN-IC-POWER_SOT23-5
PFMF.050.1: ESP32C6_VARISTORCN1812; ESP32C6_VARISTOR_CT/CN1812
Q1, Q2: 20V/4.2A/52mΩ/1.4W; ESP32_WROVER_SPARKFUN-DISCRETESEMI_SOT23-3
Q3: SI1308EDL-T1-GE3; SOT65P210X110-3N
R1, R1-PINH, R1_PINH1, R2-PINH, R2-PINH1, R4, R5, R6, R7, R8, R9, R10: 10K; ESP32_WROVER_EAGLE-LTSPICE_R0402
R1_BAT: 200; ESP32_WROVER_EAGLE-LTSPICE_R0402
R1_PWRUSB: 100K; ESP32_WROVER_EAGLE-LTSPICE_R0402
R2: 2.2; ESP32_WROVER_EAGLE-LTSPICE_R0402
R2-USB, R2-USB1: 5k1; ESP32_WROVER_EAGLE-LTSPICE_R0402
R2_BAT: 2K; ESP32_WROVER_EAGLE-LTSPICE_R0402
R3: 0.47; ESP32_WROVER_EAGLE-LTSPICE_R0402
RESET_BUTTON: BUTTON_CUSYOMV1; MYBUTTON
R_BOOT: 10K; ESP32_WROVER_EAGLE-LTSPICE_R0402
R_CAPACITOR: 15; ESP32_WROVER_EAGLE-LTSPICE_R0402
R_CHANGE: 10K; ESP32_WROVER_EAGLE-LTSPICE_R0402
R_CL1: 10K; ESP32_WROVER_EAGLE-LTSPICE_R0402
R_RESET: 10K; ESP32_WROVER_EAGLE-LTSPICE_R0402
SENSOR2: ESP32_WROVER_BME680_BME680; ESP32_WROVER_BME680_PSON80P300X300X100-8N
SJ1: SJ
TP1, TP2, TP3, TP4, TP5, TP6, TP7, TP8, TP9, TP10, TP11, TP12, TP13, TP14, TP15, TP16, TP17: TPTP20R; TP20R
U1: W25Q512JVEIQ; SON127P600X800X80-9N
U2: ESP32-C6-WROOM-1-N8; XCVR_ESP32-C6-WROOM-1-N8
U3: DS3231SN#; SOIC127P1032X265-16N
U4: MAX17048G+T10; SON50P200X200X80-9N

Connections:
3V3: C1_BAT2.1, C3.+, C9.1, D7.2 (ANODE), IC1.2 (VDD), IC4.5 (VOUT), J3.2, J4.P4 (VDD), Q2.3 (D), R1.2, R1_PINH1.2, R2-PINH1.2, R5.2, R6.2, R7.2, R8.2, R9.2, R10.2, R_BOOT.2, R_CHANGE.2, R_CL1.2, R_RESET.2, TP16.TP, U1.3 (!WP!(IO2)), U1.7 (!HOLD!/!RESET!(IO3)), U1.8 (VCC), U2.2 (3V3), U3.2 (VCC)
32KHZ: R2-PINH1.1, U2.9 (IO1), U3.1 (32KHZ)
DN: D1.4 (I/O2_2), J2.A7, J2.B7
DP: D1.6 (I/O1_2), J2.A6, J2.B6
EPD_3V3: C7.1, EPD_C5.1, J1.15, J1.16, L1.2, Q2.2 (S), TP17.TP
EPD_3V3_C: Q2.1 (G), R_CL1.1, TP13.TP, U2.18 (IO20)
EPD_BUSY: J1.9, TP9.TP, U2.26 (IO3)
EPD_CS: D6.2, J1.12, R9.1, TP10.TP, U2.11 (IO10)
EPD_DC: J1.11, TP11.TP, U2.5 (IO5)
EPD_RST: J1.10, TP12.TP, U2.21 (IO23)
FLASH_CS: D9.2, R5.1, U1.1 (!CS), U2.12 (IO11)
GDR: J1.2, Q3.1 (G), R4.2
GND: BOOT_BUTTON.2, C1.2, C1_BAT.2, C1_BAT1.2, C1_BAT2.2, C2.2, C2_BAT.2, C3.-, C4_USB.2, C5.2, C5_USB.2, C6.2, C7.2, C8.2, C9.2, C10.2, C10_SUPERCAP.1, C.1.2, CHANGE_BUTTON.2, C_DELAY.2, D3.1 (K), D6.1, D8.1, D9.1, D10.1, D11.1, D12.1, EPD_C1.2, EPD_C2.2, EPD_C5.2, EPD_C6.2, EPD_C7.2, EPD_C8.2, EPD_C9.2, EPD_C10.2, EPD_C11.2, EPD_C12.2, IC1.3 (GND), IC4.2 (VSS), J1.8, J1.17, J1.MP1, J1.MP2, J2.A1, J2.A12, J2.B1, J2.B12, J2.MP1, J2.MP2, J2.MP3, J2.MP4, J3.1, J4.G1 (GND_1), J4.G2 (GND_2), J4.G3 (GND_3), J4.G4 (GND_4), J4.P6 (VSS), MCP73831.2 (VSS), R1_PWRUSB.1, R2.1, R2-USB.2, R2-USB1.1, R2_BAT.1, R4.1, RESET_BUTTON.2, SENSOR2.1 (GND), SENSOR2.5 (SDO), SENSOR2.7 (GND), SJ1.1, TP4.TP, TP5.TP, U1.4 (GND), U1.9 (EXP), U2.1 (GND), U2.28 (GND), U2.29_1 (GND), U2.29_2 (GND), U2.29_3 (GND), U2.29_4 (GND), U2.29_5 (GND), U2.29_6 (GND), U2.29_7 (GND), U2.29_8 (GND), U2.29_9 (GND), U3.13 (GND), U4.1 (CTG), U4.4 (GND), U4.6 (QSTRT), U4.9 (EP)
GPIO8: R1.1, U2.10 (IO8)
I2C_PW: C2.1, C.1.1, R1-PINH.2, R2-PINH.2, SENSOR2.2 (CSB), SENSOR2.6 (VDDIO), SENSOR2.8 (VDD), U2.17 (IO19)
INT_RTC: R1_PINH1.1, TP15.TP, U2.8 (IO0), U3.3 (SQW/!INT)
IO/BOOT: BOOT_BUTTON.3, BOOT_BUTTON.4, C6.1, R_BOOT.1, U2.15 (IO9)
IO/CHANGE: C10.1, CHANGE_BUTTON.3, CHANGE_BUTTON.4, R_CHANGE.1, U2.23 (IO15)
MISO: D12.2, J4.P7 (DAT0), R8.1, TP6.TP, U1.2 (DO(IO1)), U2.27 (IO2)
MOSI: D11.2, J1.14, J4.P3 (CMD), R7.1, TP7.TP, U1.5 (DI(IO0)), U2.7 (IO7)
unnamed: C1.1, C_DELAY.1, IC1.5 (CT)
unnamed: J2.B5, R2-USB.1
unnamed: EPD_C2.1, J1.5
unnamed: J2.A5, R2-USB1.2
unnamed: CHG_LED.C, R1_BAT.1
unnamed: C1_BAT1.1, D2.1 (CATHODE), IC4.1 (VIN), IC4.3 (CE), Q1.2 (S)
unnamed: C4.1, D3.2 (A), D4.1 (K)
unnamed: MCP73831.1 (STAT), R1_BAT.2
unnamed: MCP73831.5 (PROG), R2_BAT.2
unnamed: EPD_C1.1, J1.4
unnamed: EPD_C6.1, J1.18
unnamed: EPD_C7.1, J1.19
unnamed: EPD_C8.1, J1.20
unnamed: EPD_C10.1, J1.22
unnamed: EPD_C12.1, J1.24
unnamed: D7.1 (CATHODE), R_CAPACITOR.2
PREVGH: D5.1 (K), EPD_C9.1, J1.21
PREVGL: D4.2 (A), EPD_C11.1, J1.23
RESE: J1.3, Q3.2 (S), R3.2
RESE': R2.2, R3.1, SJ1.2
RESET: C5.1, IC1.1 (VOUT), RESET_BUTTON.3, RESET_BUTTON.4, R_RESET.1, U2.3 (EN)
RTC_RST: U2.16 (IO18), U3.4 (!RST)
RX: TP2.TP, U2.24 (RXD0/GPIO17)
SCK: D10.2, J1.13, J4.P5 (CLK), R6.1, TP8.TP, U1.6 (CLK), U2.6 (IO6)
SCL: J3.4, R2-PINH.1, SENSOR2.4 (SCK), U2.20 (IO22), U3.16 (SCL), U4.7 (SCL)
SDA: J3.3, R1-PINH.1, SENSOR2.3 (SDI), U2.19 (IO21), U3.15 (SDA), U4.8 (SDA)
SRC: C4.2, D5.2 (A), L1.1, Q3.3 (D)
SS_SD: D8.2, J4.P2 (CD/DAT3), R10.1, U2.4 (IO4)
TX: TP1.TP, U2.25 (TXD0/GPIO16)
USB_D+: D1.1 (I/O1_1), U2.14 (IO13)
USB_D-: D1.3 (I/O2_1), U2.13 (IO12)
VBAT: C2_BAT.1, MCP73831.3 (VBAT), Q1.3 (D), TP3.TP, U4.2 (CELL), U4.3 (VDD)
VBUS: C1_BAT.1, C4_USB.1, C5_USB.1, CHG_LED.A, D1.5 (VBUS), D2.2 (ANODE), MCP73831.4 (VIN), PFMF.050.1.2, Q1.1 (G), R1_PWRUSB.2, TP14.TP
VRTC: C8.1, C10_SUPERCAP.2, R_CAPACITOR.1, U3.14 (VBAT)
VUSB: J2.A4, J2.A9, J2.B4, J2.B9, PFMF.050.1.1

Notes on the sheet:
USB C connector & ESD protection
LDO Voltage Regulator
SD Card
Display Type Selector
E-Paper Drive Circuit
Li-Po Battery Charging Controller
ESP32 C6
E-Paper Display Header
EPD Power
Environmental Sensor BME688
Voltage Supervisor + Reset & Boot / IO Button
Battery Charge Level
RTC Module DS3231SN
Test Pads
Qwiic / Stemma QT
SPI ESD Protection Lines
External NOR Flash 64MB
OpenBook Schematic
Drawn by: Rares Tanase

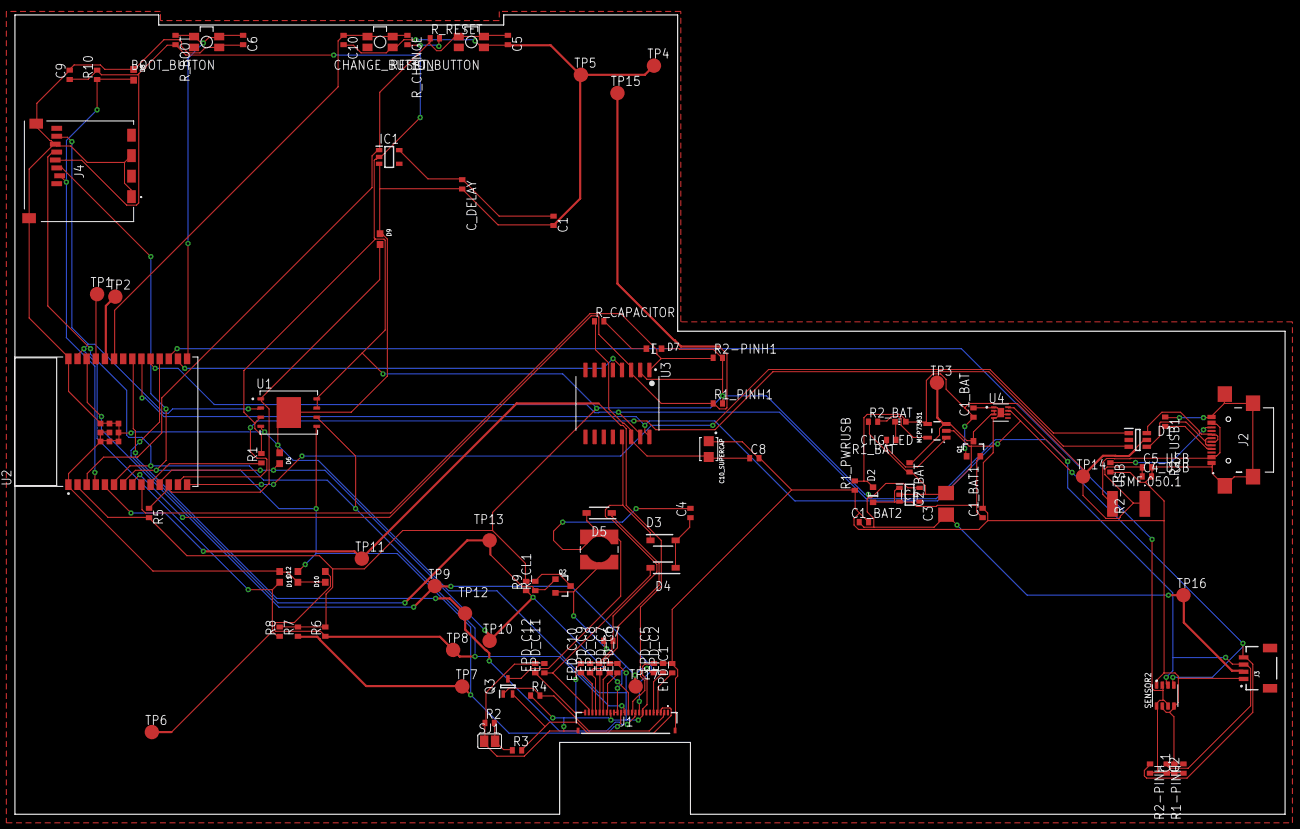
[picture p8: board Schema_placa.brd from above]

Board: 2 copper layers, 176.7 x 111.2 mm, 104 parts (0 on the bottom side), 55 nets.

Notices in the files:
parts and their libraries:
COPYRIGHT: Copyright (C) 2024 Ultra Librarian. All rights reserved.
